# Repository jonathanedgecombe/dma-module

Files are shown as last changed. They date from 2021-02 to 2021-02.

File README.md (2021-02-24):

A DMA module designed for the RC2014.

### BOM
- 1x Z84C1008PEG (IC1)
- 1x 74HCT688N (IC2)
- 1x 74LS157N (IC3)
- 1x 2x40 90 degree pin header (JP1)
- 3x 1x3 90 degree pin header (JP2, JP3, JP5)
- 2x 1x2 90 degree pin header (JP4, JP6)
- 3x 100nF 2.54mm ceramic capacitors (C1, C2, C3)
- 1x 10K 8-resistor bussed network (RN1)
- 1x MCNDP-08V 8-way DIP switch (S1)

### Board photos and renders

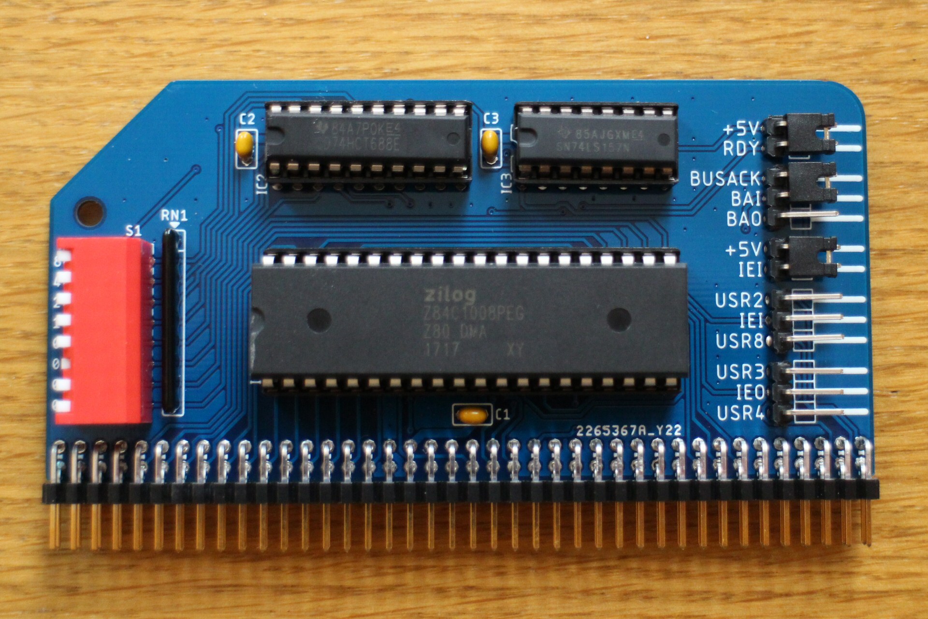
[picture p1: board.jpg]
Board photo


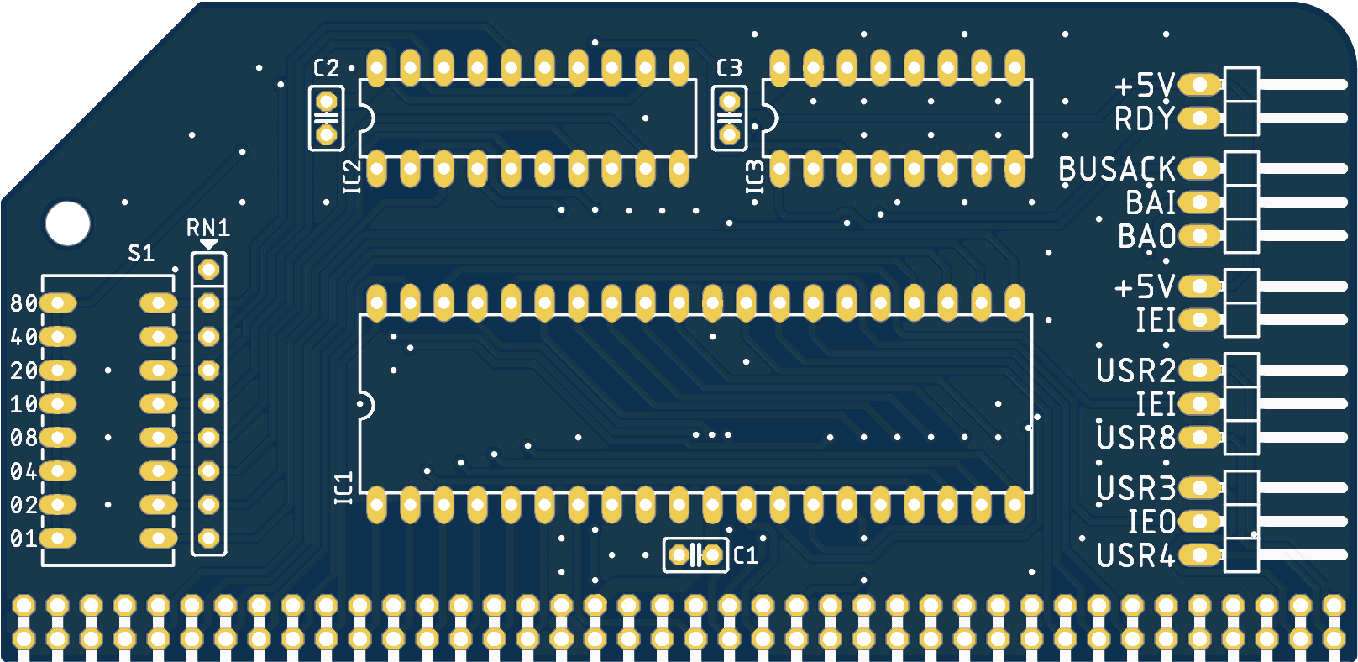
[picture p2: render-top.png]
Board render


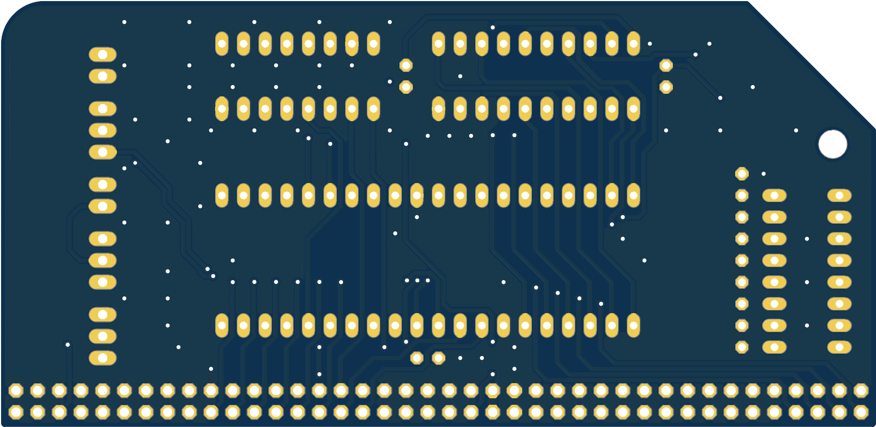
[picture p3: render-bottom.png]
Board render bottom


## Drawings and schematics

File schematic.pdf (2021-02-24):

A

A

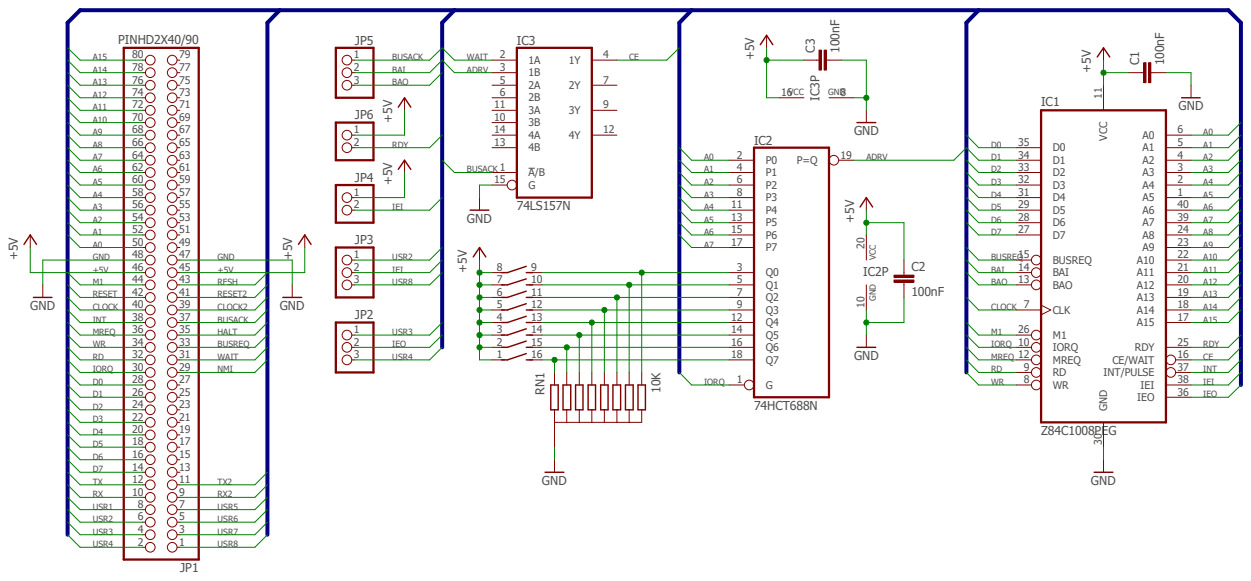
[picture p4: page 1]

GND ⁺⁵V GND +⁵V

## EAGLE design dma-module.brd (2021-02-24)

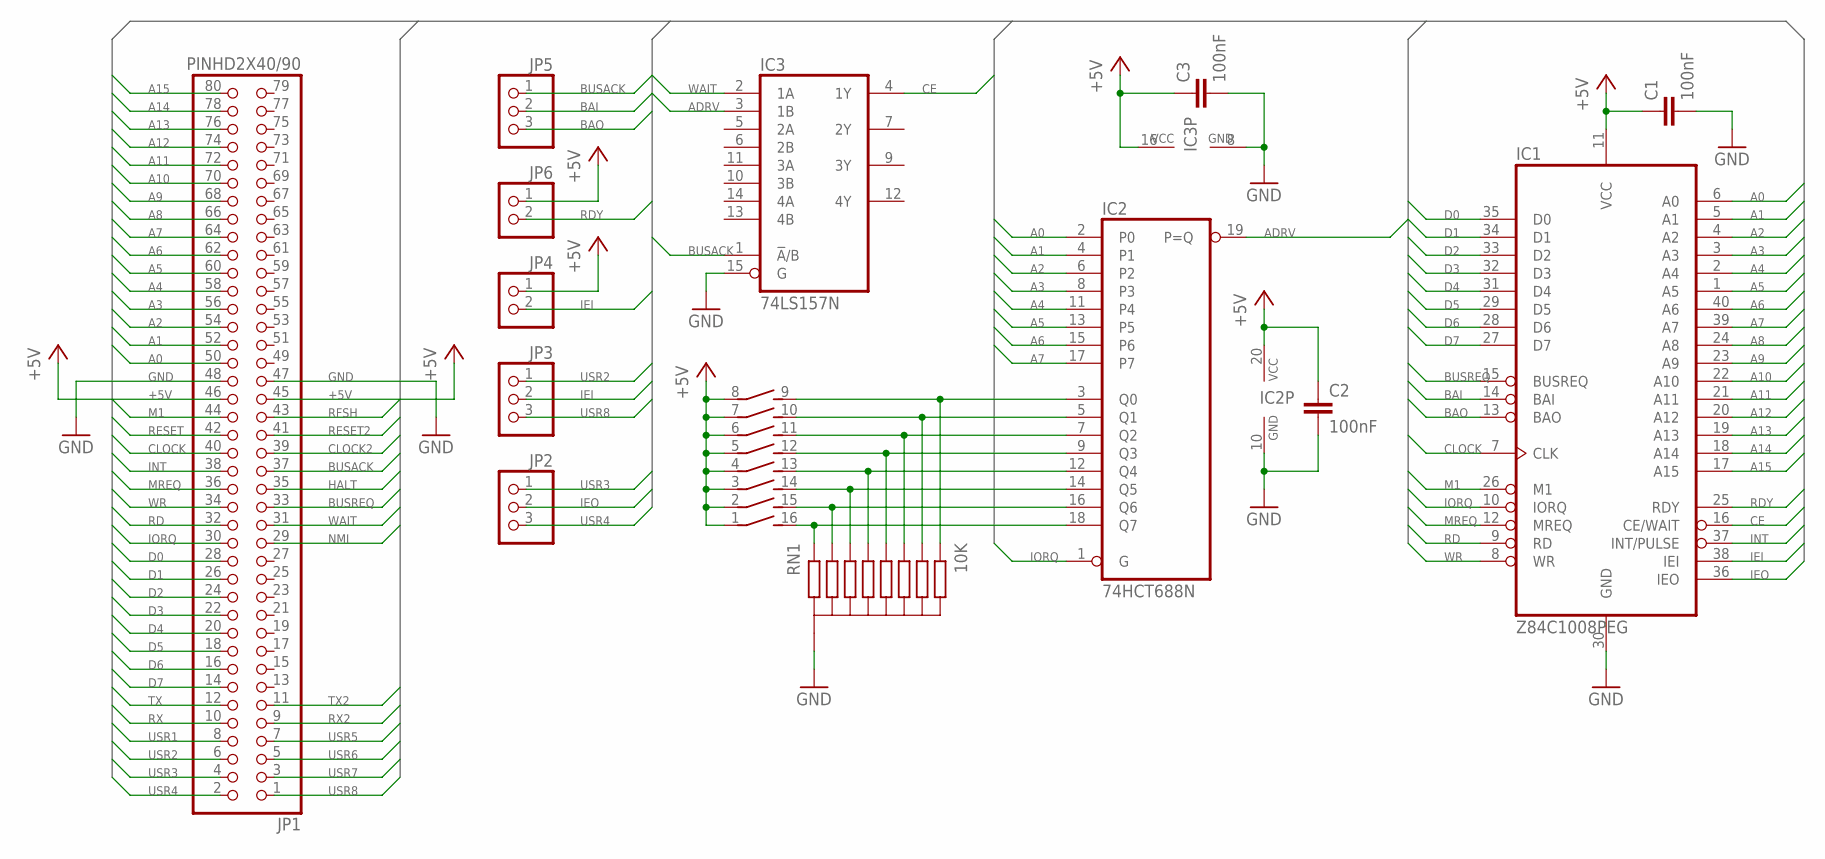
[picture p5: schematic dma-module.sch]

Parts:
C1, C2, C3: 100nF; C025-025X050
IC1: Z84C1008PEG; DIP40
IC2: 74HCT688N; DIL20
IC3: 74LS157N; DIL16
JP1: PINHD2X40/90; 2X40/90
JP2, JP3, JP5: PINHD-1X3/90; 1X03/90
JP4, JP6: PINHD-1X2/90; 1X02/90
RN1: 10K; RBUS
S1: DIP08SB

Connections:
+5V: C1.1, C2.1, C3.1, IC1.11 (VCC), IC2.20 (VCC), IC3.16 (VCC), JP1.45, JP1.46, JP4.1, JP6.1, S1.1, S1.2 (1), S1.3 (1), S1.4 (1), S1.5 (1), S1.6 (1), S1.7 (1), S1.8 (1)
A0: IC1.6 (A0), IC2.2 (P0), JP1.50
A1: IC1.5 (A1), IC2.4 (P1), JP1.52
A2: IC1.4 (A2), IC2.6 (P2), JP1.54
A3: IC1.3 (A3), IC2.8 (P3), JP1.56
A4: IC1.2 (A4), IC2.11 (P4), JP1.58
A5: IC1.1 (A5), IC2.13 (P5), JP1.60
A6: IC1.40 (A6), IC2.15 (P6), JP1.62
A7: IC1.39 (A7), IC2.17 (P7), JP1.64
A8: IC1.24 (A8), JP1.66
A9: IC1.23 (A9), JP1.68
A10: IC1.22 (A10), JP1.70
A11: IC1.21 (A11), JP1.72
A12: IC1.20 (A12), JP1.74
A13: IC1.19 (A13), JP1.76
A14: IC1.18 (A14), JP1.78
A15: IC1.17 (A15), JP1.80
ADRV: IC2.19 (P=Q), IC3.3 (1B)
BAI: IC1.14 (BAI), JP5.2
BAO: IC1.13 (BAO), JP5.3
BUSACK: IC3.1 (!A!/B), JP1.37, JP5.1
BUSREQ: IC1.15 (BUSREQ), JP1.33
CE: IC1.16 (CE/WAIT), IC3.4 (1Y)
CLOCK: IC1.7 (CLK), JP1.40
CLOCK2: JP1.39
D0: IC1.35 (D0), JP1.28
D1: IC1.34 (D1), JP1.26
D2: IC1.33 (D2), JP1.24
D3: IC1.32 (D3), JP1.22
D4: IC1.31 (D4), JP1.20
D5: IC1.29 (D5), JP1.18
D6: IC1.28 (D6), JP1.16
D7: IC1.27 (D7), JP1.14
GND: C1.2, C2.2, C3.2, IC1.30 (GND), IC2.10 (GND), IC3.8 (GND), IC3.15 (G), JP1.47, JP1.48, RN1.P$1 (COM)
HALT: JP1.35
IEI: IC1.38 (IEI), JP3.2, JP4.2
IEO: IC1.36 (IEO), JP2.2
INT: IC1.37 (INT/PULSE), JP1.38
IORQ: IC1.10 (IORQ), IC2.1 (G), JP1.30
M1: IC1.26 (M1), JP1.44
MREQ: IC1.12 (MREQ), JP1.36
unnamed: IC2.3 (Q0), RN1.P$9 (R8), S1.9 (2)
unnamed: IC2.5 (Q1), RN1.P$8 (R7), S1.10 (2)
unnamed: IC2.7 (Q2), RN1.P$7 (R6), S1.11 (2)
unnamed: IC2.9 (Q3), RN1.P$6 (R5), S1.12 (2)
unnamed: IC2.12 (Q4), RN1.P$5 (R4), S1.13 (2)
unnamed: IC2.14 (Q5), RN1.P$4 (R3), S1.14 (2)
unnamed: IC2.16 (Q6), RN1.P$3 (R2), S1.15 (2)
unnamed: IC2.18 (Q7), RN1.P$2 (R1), S1.16 (2)
NMI: JP1.29
RD: IC1.9 (RD), JP1.32
RDY: IC1.25 (RDY), JP6.2
RESET: JP1.42
RESET2: JP1.41
RFSH: JP1.43
RX: JP1.10
RX2: JP1.9
TX: JP1.12
TX2: JP1.11
USR1: JP1.8
USR2: JP1.6, JP3.1
USR3: JP1.4, JP2.1
USR4: JP1.2, JP2.3
USR5: JP1.7
USR6: JP1.5
USR7: JP1.3
USR8: JP1.1, JP3.3
WAIT: IC3.2 (1A), JP1.31
WR: IC1.8 (WR), JP1.34

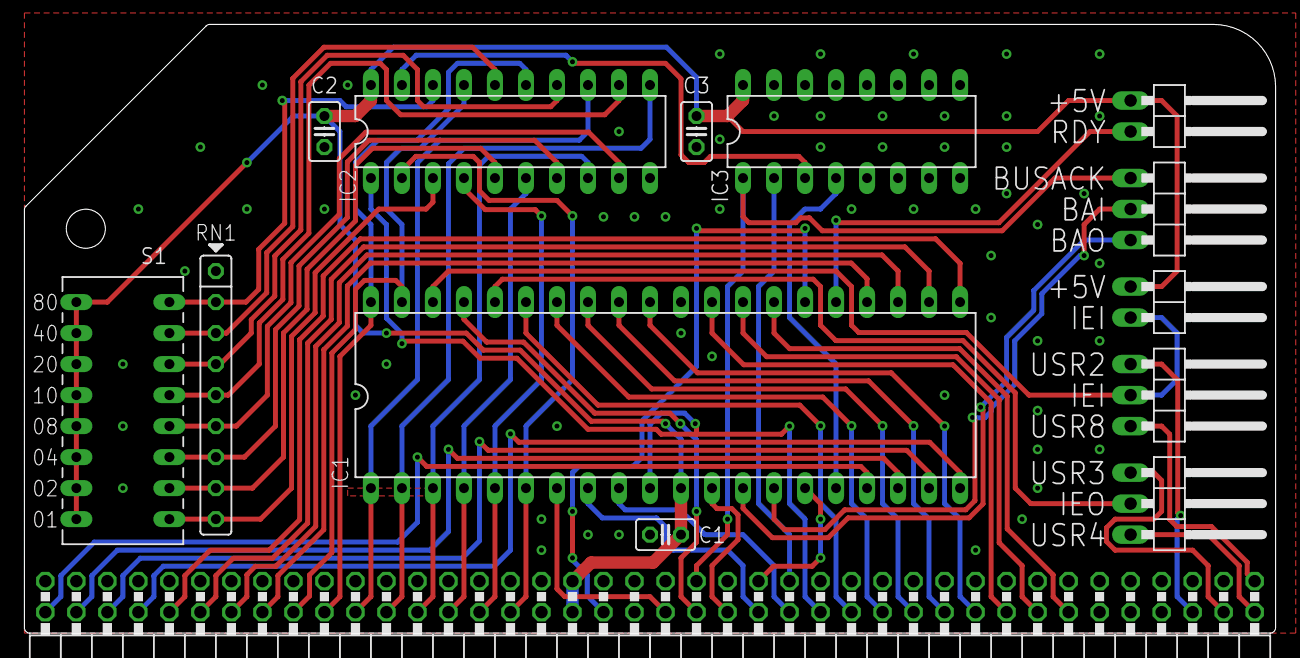
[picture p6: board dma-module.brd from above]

Board: 2 copper layers, 102.5 x 49.9 mm, 14 parts (0 on the bottom side), 55 nets.

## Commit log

2021-02-24 Add board photo
2021-02-24 Add BOM to readme
